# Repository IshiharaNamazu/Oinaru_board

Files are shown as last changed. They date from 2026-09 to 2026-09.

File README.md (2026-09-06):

# Oinaru Board

Oinaru Boardは、USB Type-Cからセンサへ電源を供給しながら、PCとセンサ間のUSB–RS485通信を行うための変換基板です。

USB Type-Cから入力された電圧は、XC9306昇降圧DC-DCコンバータモジュールで5 Vに安定化してセンサへ供給します。

USB–UART変換にはCH340E、差動信号の送受信には2個のMAX485Eを使用し、TX±／RX±による4線式通信に対応しています。

## 特長

- USB Type-C（USB 2.0）接続
- センサへの5 V電源供給
- XC9306モジュールによるUSB入力電圧の昇降圧・安定化
- USB–RS485変換
- TX±／RX±の4線式全二重通信
- USB接続および5 V電源のLED表示
- 通信線の終端抵抗を実装可能

## 基板外観

### 表面

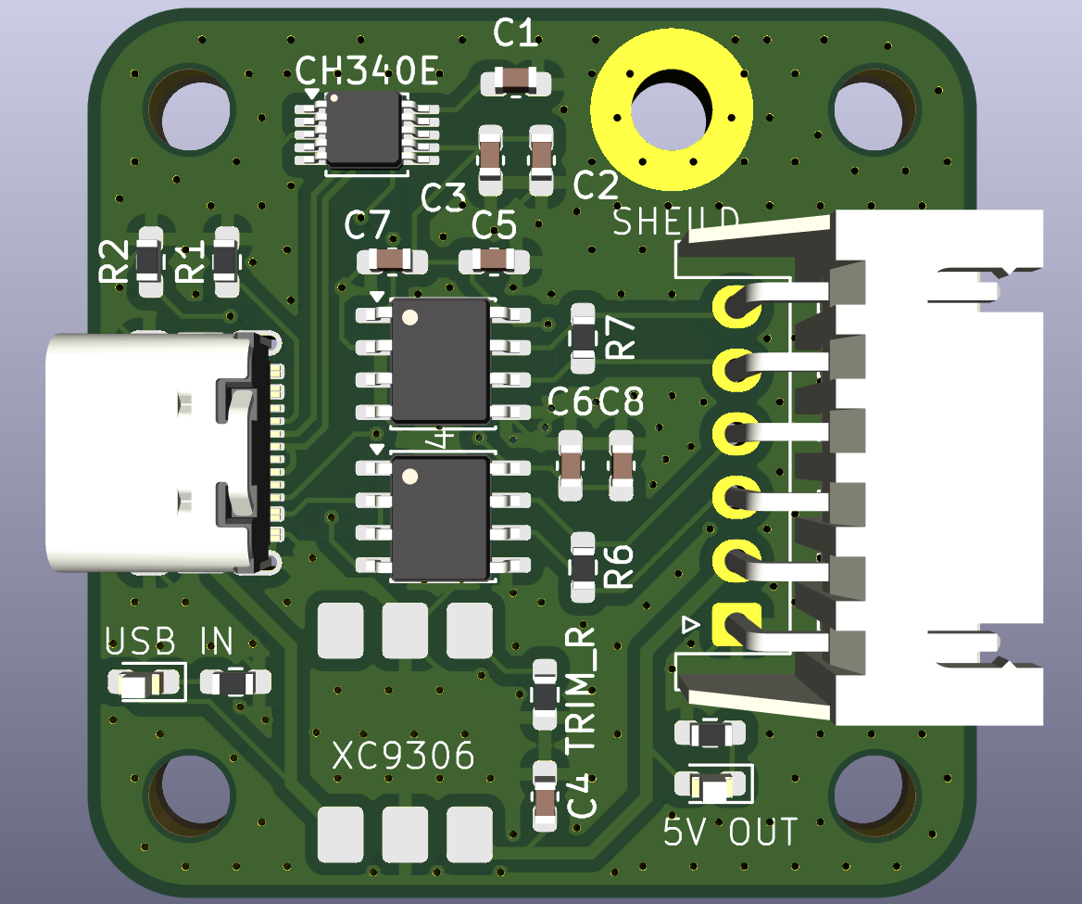
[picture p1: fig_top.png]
Oinaru Board 表面


### 裏面

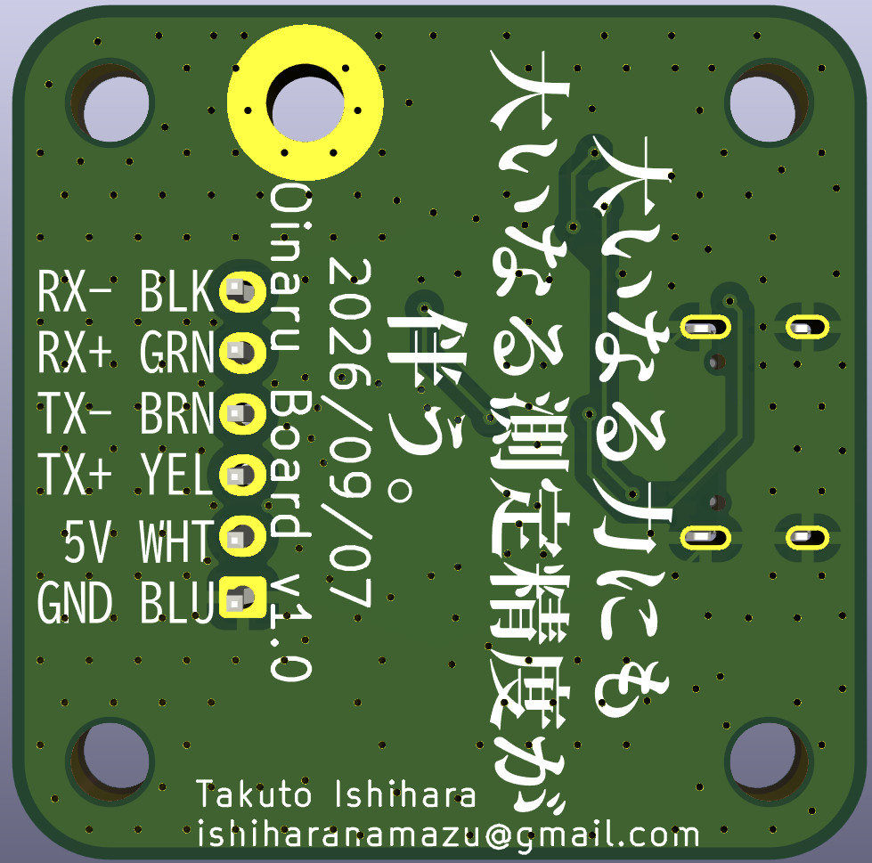
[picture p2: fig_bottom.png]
Oinaru Board 裏面


## センサ側コネクタ（XH）

| ピン | 信号 |
| ---: | :--- |
| 1 | GND |
| 2 | +5 V |
| 3 | TX+ |
| 4 | TX- |
| 5 | RX+ |
| 6 | RX- |

ピン番号はKiCadの回路図・基板データ上の番号です。実際に接続する前に、使用するセンサの仕様書と信号方向・ピン配列を照合してください。
基盤のTXはセンサのRXと接続されることに注意してください

## 使用方法

1. XHコネクタにセンサを接続します。
2. Oinaru BoardとPCをUSB Type-Cケーブルで接続します。
3. PCに認識されたCH340Eのシリアルポートを、使用するソフトウェアから開きます。
4. センサの仕様に合わせて通信速度などを設定し、通信を開始します。

## 主な構成部品

| 部品 | 用途 |
| :--- | :--- |
| CH340E | USB–UART変換 |
| MAX485E × 2 | TX／RX差動信号変換 |
| XC9306昇降圧モジュール | USB入力電圧を5 Vに安定化 |
| USB Type-Cレセプタクル | PC接続・電源入力 |
| 6ピンコネクタ | センサ接続 |

## オプション部品

以下の部品は必要に応じて実装するオプションです。

- `TRIM_R`：XC9306モジュールの出力電圧調整用抵抗です。使用するモジュールの仕様と必要な出力電圧に合わせて抵抗値を選定します。
- `R6`：TX差動信号線の終端抵抗です。必要に応じて実装します。
- `R7`：RX差動信号線の終端抵抗です。必要に応じて実装します。

## 設計データ

- `usb_rs485_adapter.kicad_pro`：KiCadプロジェクト
- `usb_rs485_adapter.kicad_sch`：回路図
- `usb_rs485_adapter.kicad_pcb`：基板レイアウト
- `production/`：製造用出力データ

## 注意事項

- 本基板の通信部と電源部は絶縁されていません。
- センサの消費電流が、接続するUSBポートやケーブルの給電能力を超えないことを確認してください。
- 配線の誤りや極性の取り違えは、基板・センサ・PCの故障につながる可能性があります。
- 使用環境に応じて終端抵抗の値と実装状態を確認してください。

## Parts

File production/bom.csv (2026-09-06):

Designator | Footprint | Quantity | Value | LCSC Part #
C1, C3 | 0603 | 2 | 0.1u
C2, C4, C7, C8 | 0603 | 4 | 22u
C5, C6 | 0603 | 2 | 0.1
D1 | 0603 | 1 | USB
D2 | 0603 | 1 | 5V
J1 | USB_C_Receptacle_GCT_USB4105-xx-A_16P_TopMnt_Horizontal | 1 | USB_C_Receptacle_USB2.0_16P
J2 | JST_XH_S6B-XH-A_1x06_P2.50mm_Horizontal | 1 | Conn_01x06_Pin
R1, R2 | 0603 | 2 | 5.1k
R3, R4 | 0603 | 2 | 10k
R5 | 0603 | 1 | INF
R6, R7 | 0603 | 2 | TRM
U1, U3 | SOIC-8_3.9x4.9mm_P1.27mm | 2 | MAX485E
U2 | MSOP-10_3x3mm_P0.5mm | 1 | CH340E
U4 | AE-XC9306-5V0 | 1 | ~

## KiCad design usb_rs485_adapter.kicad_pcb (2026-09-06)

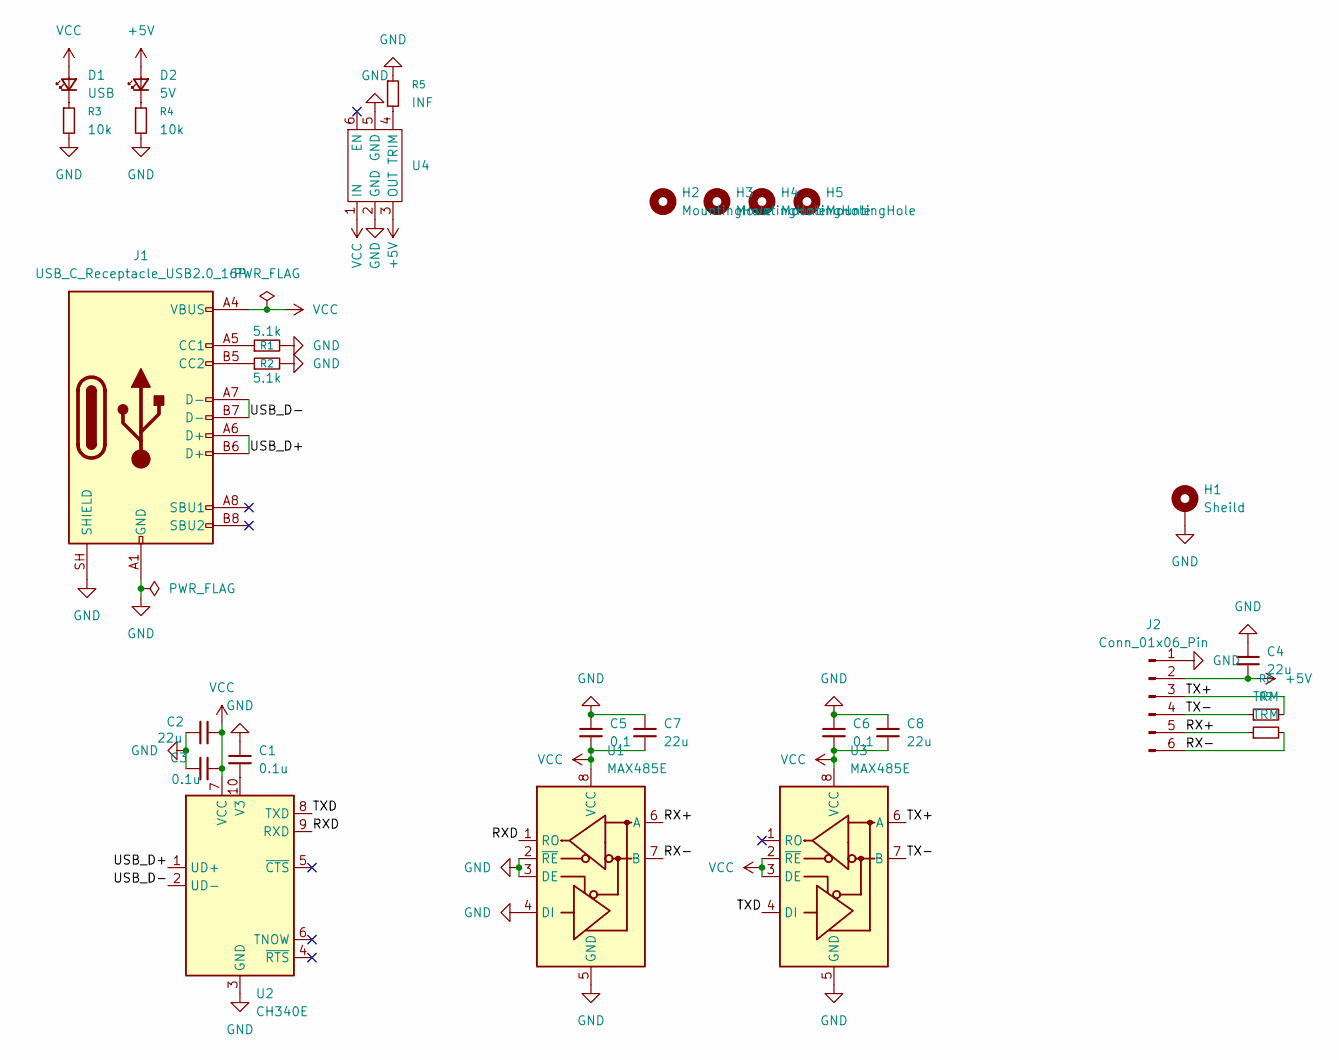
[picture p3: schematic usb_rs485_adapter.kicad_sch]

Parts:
C1, C3: 0.1u; C_0603_1608Metric_Pad1.08x0.95mm_HandSolder
C2, C4, C7, C8: 22u; C_0603_1608Metric_Pad1.08x0.95mm_HandSolder
C5, C6: 0.1; C_0603_1608Metric_Pad1.08x0.95mm_HandSolder
D1: USB; LED_0603_1608Metric_Pad1.05x0.95mm_HandSolder
D2: 5V; LED_0603_1608Metric_Pad1.05x0.95mm_HandSolder
H1: Sheild; MountingHole_3.2mm_M3_Pad
H2, H3, H4, H5: MountingHole; MountingHole_3.2mm_M3
J1: USB_C_Receptacle_USB2.0_16P; USB_C_Receptacle_GCT_USB4105-xx-A_16P_TopMnt_Horizontal
J2: Conn_01x06_Pin; JST_XH_S6B-XH-A_1x06_P2.50mm_Horizontal
R1, R2: 5.1k; R_0603_1608Metric_Pad0.98x0.95mm_HandSolder
R3, R4: 10k; R_0603_1608Metric_Pad0.98x0.95mm_HandSolder
R5: INF; R_0603_1608Metric_Pad0.98x0.95mm_HandSolder
R6, R7: TRM; R_0603_1608Metric_Pad0.98x0.95mm_HandSolder
U1, U3: MAX485E; SOIC-8_3.9x4.9mm_P1.27mm
U2: CH340E; MSOP-10_3x3mm_P0.5mm
U4: AE-XC9306-5V0

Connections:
+5V: C4.1, D2.2 (A), J2.2, U4.3 (OUT)
/RX+: J2.5, R7.1, U1.6 (A)
/RX-: J2.6, R7.2, U1.7 (B)
/RXD: U1.1 (RO), U2.9 (RXD)
/TX+: J2.3, R6.2, U3.6 (A)
/TX-: J2.4, R6.1, U3.7 (B)
/TXD: U2.8 (TXD), U3.4 (DI)
/USB_D+: J1.A6 (D+), J1.B6 (D+), U2.1 (UD+)
/USB_D-: J1.A7 (D-), J1.B7 (D-), U2.2 (UD-)
GND: C1.1, C2.1, C3.1, C4.2, C5.2, C6.1, C7.1, C8.1, H1.1 (1_1), J1.A1 (GND), J1.A12 (GND), J1.B1 (GND), J1.B12 (GND), J1.SH (SHIELD), J2.1, R1.2, R2.2, R3.2, R4.2, R5.1, U1.2 (~RE), U1.3 (DE), U1.4 (DI), U1.5 (GND), U2.3 (GND), U3.5 (GND), U4.2 (GND), U4.5 (GND)
unnamed: D1.1 (K), R3.1
unnamed: D2.1 (K), R4.1
unnamed: J1.A5 (CC1), R1.1
unnamed: J1.B5 (CC2), R2.1
unnamed: C1.2, U2.10 (V3)
unnamed: R5.2, U4.4 (TRIM)
VCC: C2.2, C3.2, C5.1, C6.2, C7.2, C8.2, D1.2 (A), J1.A4 (VBUS), J1.A9 (VBUS), J1.B4 (VBUS), J1.B9 (VBUS), U1.8 (VCC), U2.7 (VCC), U3.2 (~RE), U3.3 (DE), U3.8 (VCC), U4.1 (IN)

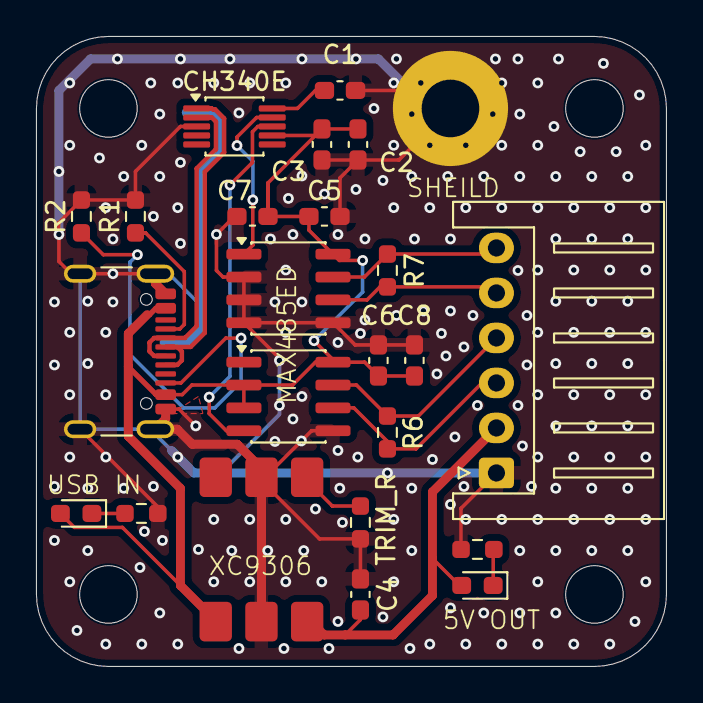
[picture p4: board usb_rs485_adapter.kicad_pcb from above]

Board: 2 copper layers, 35.0 x 35.0 mm, 28 parts (0 on the bottom side), 17 nets.

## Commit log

2026-09-06 自動配線前
    [temp-freerouting.dsn, usb_rs485_adapter.dsn, usb_rs485_adapter.kicad_pcb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]
2026-09-06 パーツが基盤ギリギリ過ぎた
    [usb_rs485_adapter.dsn, usb_rs485_adapter.kicad_pcb]
2026-09-06 v1.0完成
    [bom.csv, designators.csv, positions.csv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]
2026-09-06 オプション部品
2026-09-06 シルク微修正
    [usb_rs485_adapter.kicad_pcb]
